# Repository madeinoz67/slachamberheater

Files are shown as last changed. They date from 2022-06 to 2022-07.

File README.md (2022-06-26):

# STR-21-007-SLAChamberHeater

SLA Chamber Heater for Resin Printers

## Project Features

* STR-21-007-SLAChamberHeater
* A starter KiCad project structured similar to <https://hackaday.com/2017/05/18/kicad-best-practises-library-management/>
* A starter documentation structure based on the <https://hutscape.com/pine/> by Sayanee Basu <https://github.com/sayanee> and her great youtube video around hardware documentation <https://youtu.be/uPitFGqjyPU>.

## Resources

Below are some handy resource links.

* [KiCad](https://www.kicad.org/) is a Cross Platform and Open Source Electronics Design Automation suite.
* [cookiecutter-kicad](https://github.com/madeinoz67/cookiecutter-kicad) a cookiecutter template for KiCad Projects.

## Authors

* **Stephen Eaton** - *Initial Work* - [github](https://github.com/madeinoz67)

See also the list of [contributors](https://github.com/madeinoz67/slachamberheater/AUTHORS.rst) who participated in this project.

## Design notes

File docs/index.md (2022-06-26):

# Welcome to STR-21-007-SLAChamberHeater

SLA Chamber Hearter for Resin Printers

--8<-- "./README.md"

    mkdocs.yml    # The configuration file.
    docs/
        index.md  # The documentation homepage.
        ...       # Other markdown pages, images and other files.

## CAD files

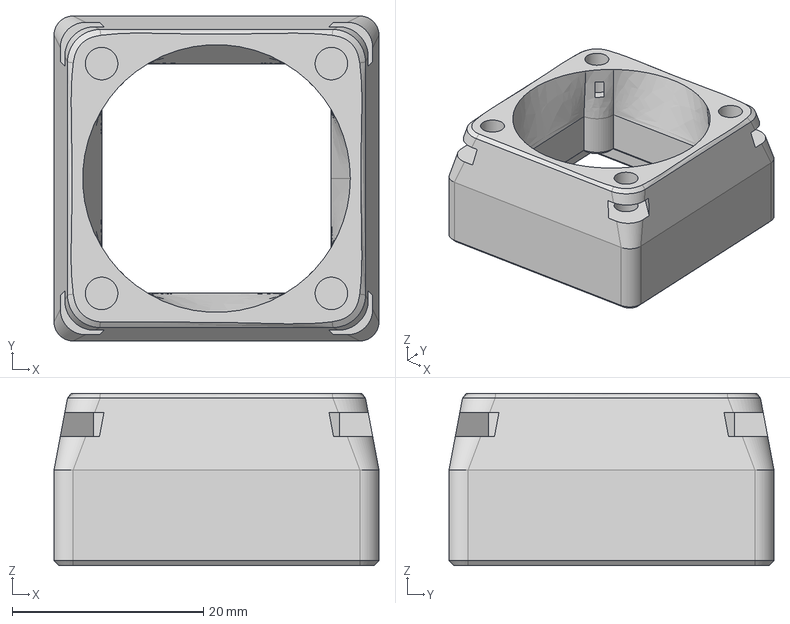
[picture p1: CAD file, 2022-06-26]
cad/V4/working/STR-21-007_assembly-rework2.FCStd
34.0 x 34.0 x 18.0 mm

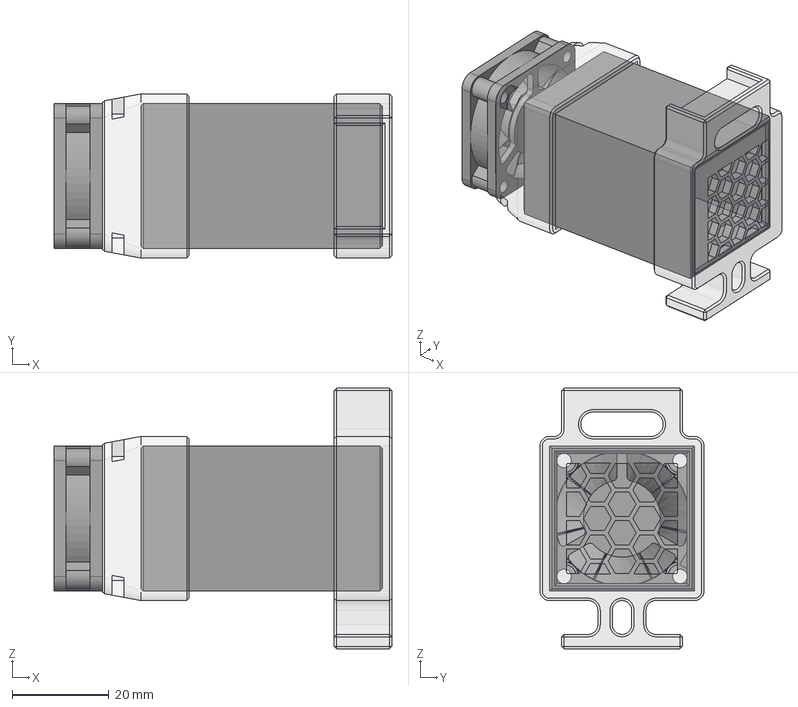
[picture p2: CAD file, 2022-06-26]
cad/V4/STR-21-007_assembly.FCStd
70.0 x 34.0 x 54.0 mm
InletBody
OutlerBody

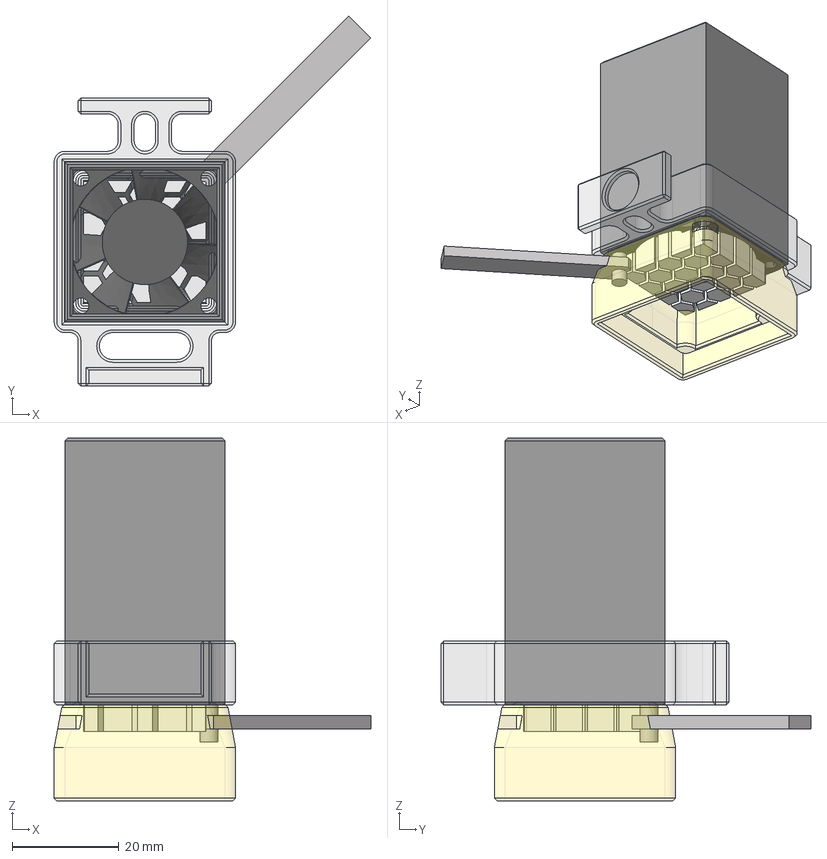
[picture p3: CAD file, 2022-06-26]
cad/V4/working/STR-21-007_assembly-rework1.FCStd
59.4 x 69.4 x 68.0 mm
Binder(Boolean001)
Binder001(Boolean001)
Binder002(BaseFeature)
M3 bolt and grooved nut
HoneycombBody
OutlerBody

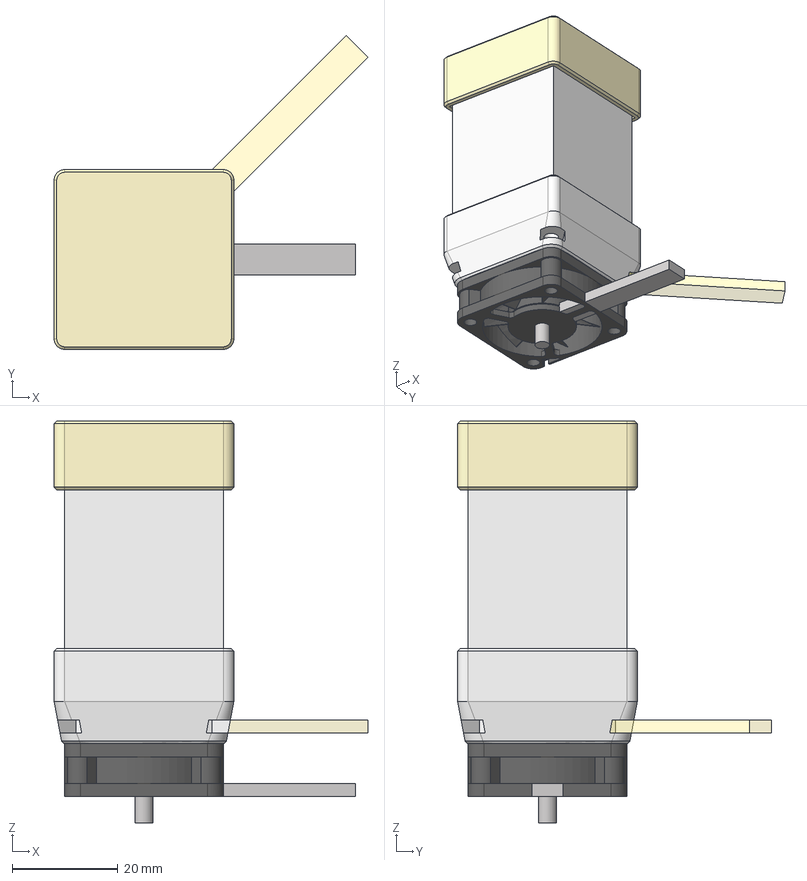
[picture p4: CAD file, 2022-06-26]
cad/V4/STR-21-007.FCStd
59.3 x 59.3 x 76.0 mm
Binder(_3mmNut)
Inlet_Housing_Body
TubeBody
BooleanBody
Chamfer001Body
M3 bolt and grooved nut
Import004(Chamfer001)
OutletHousingBody
Pad001Body

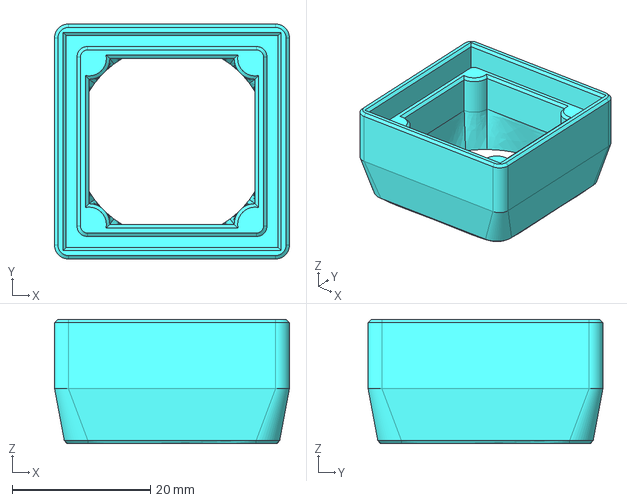
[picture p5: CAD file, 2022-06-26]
cad/V4/V4.1/STR-21-007.FCStd
34.0 x 34.0 x 18.0 mm

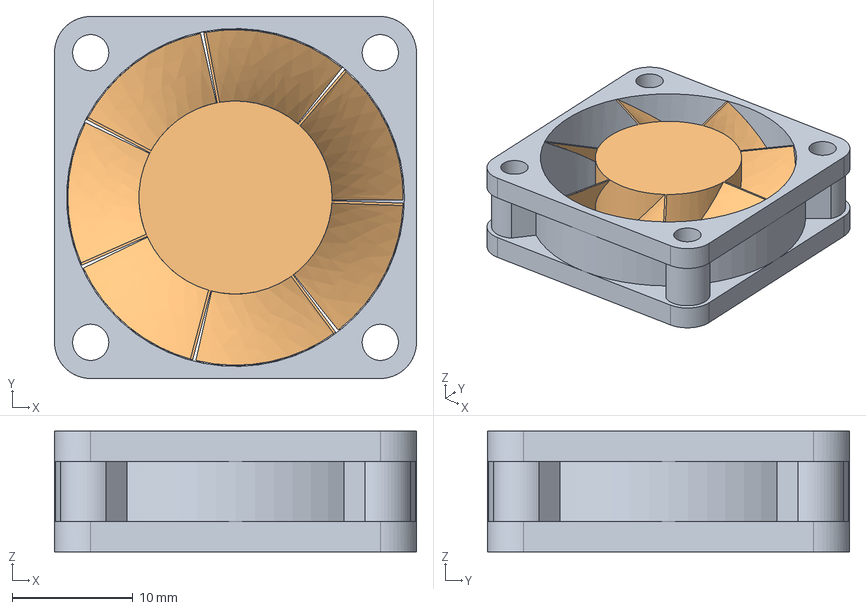
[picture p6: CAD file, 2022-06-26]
cad/Parts/30mmFan.FCStd
30.0 x 30.0 x 10.0 mm

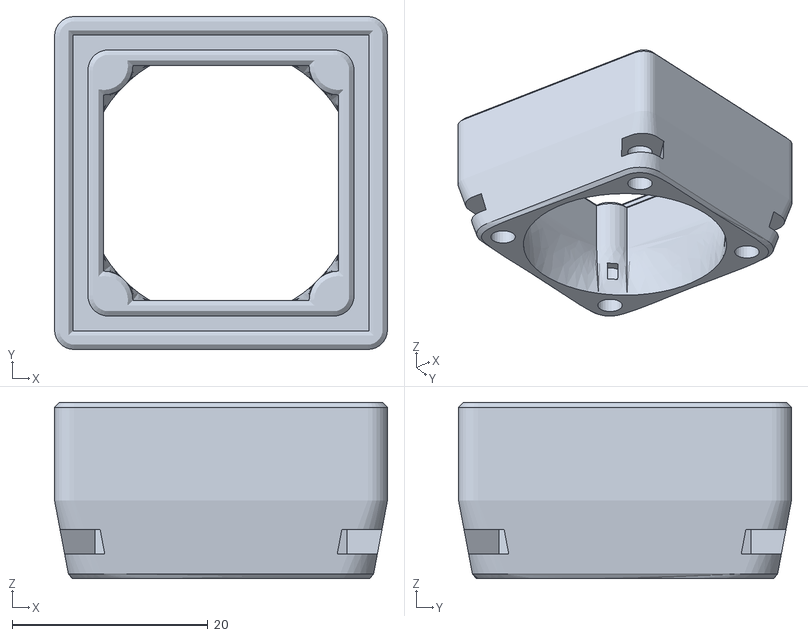
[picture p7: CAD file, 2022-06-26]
cad/STR-21-007-Resin_Heater--master_heater.stl
34.0 x 34.0 x 18.0

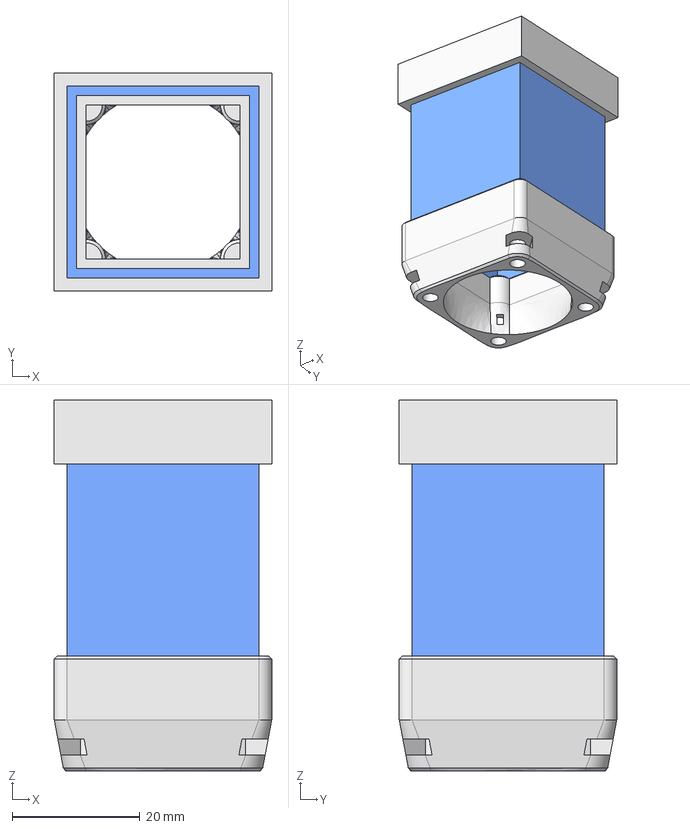
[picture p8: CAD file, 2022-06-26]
cad/STR-21-007-Resin_Heater.FCStd
34.0 x 34.0 x 58.0 mm
Inlet_housing
AL_sqrtube30x30
Outlet_housing

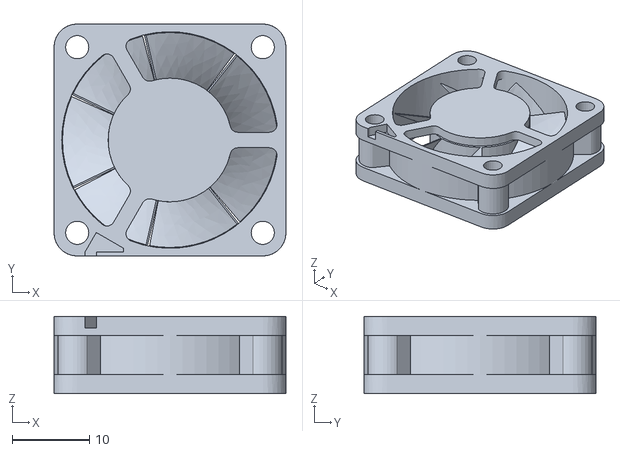
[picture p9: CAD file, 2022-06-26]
cad/STR-21-007-Resin_Heater--30mm_Axial_Fan.stl
30.0 x 30.0 x 10.0

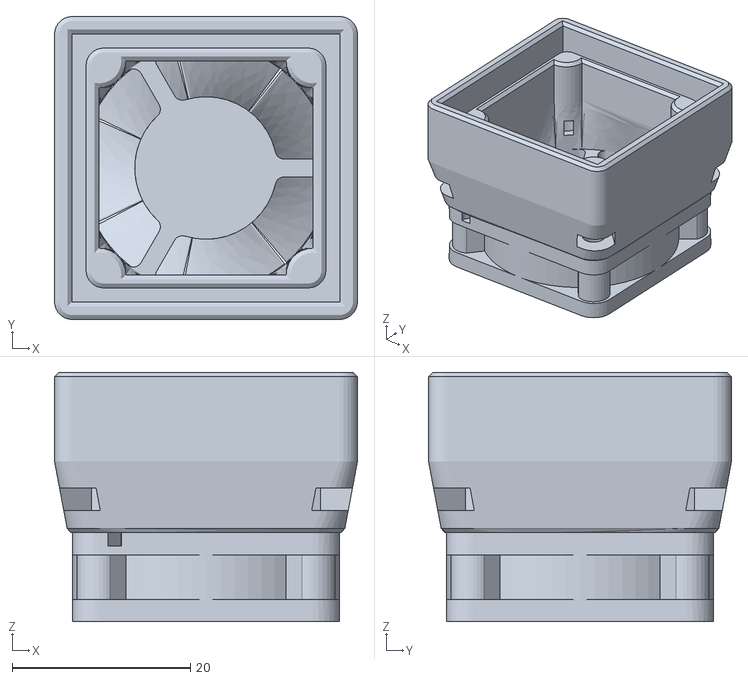
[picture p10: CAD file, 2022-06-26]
cad/STR-21-007-Resin_Heater--Resin_Heater.stl
34.0 x 34.0 x 28.0

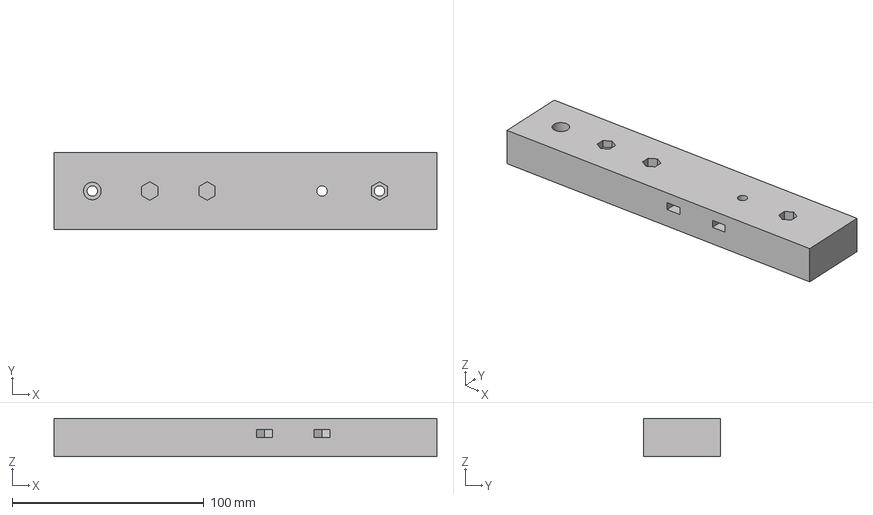
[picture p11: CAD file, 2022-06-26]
cad/Parts/Bolts and nuts holes.FCStd
200.0 x 40.0 x 20.0 mm

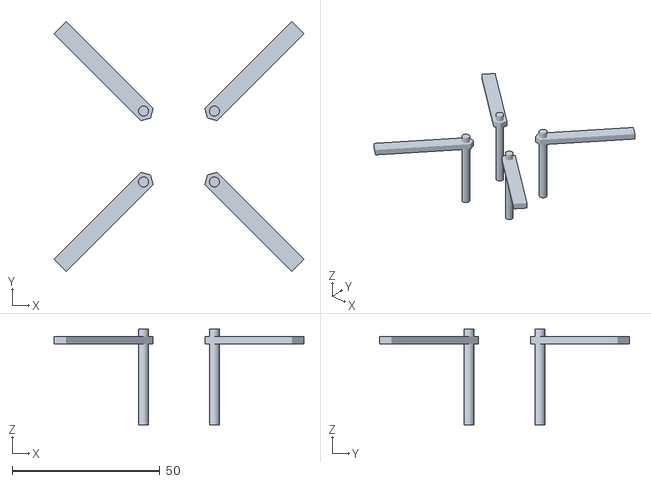
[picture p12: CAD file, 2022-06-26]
cad/STR-21-007-Resin_Heater--Reference(M3 Nut Tool).stl
84.7 x 84.7 x 32.5

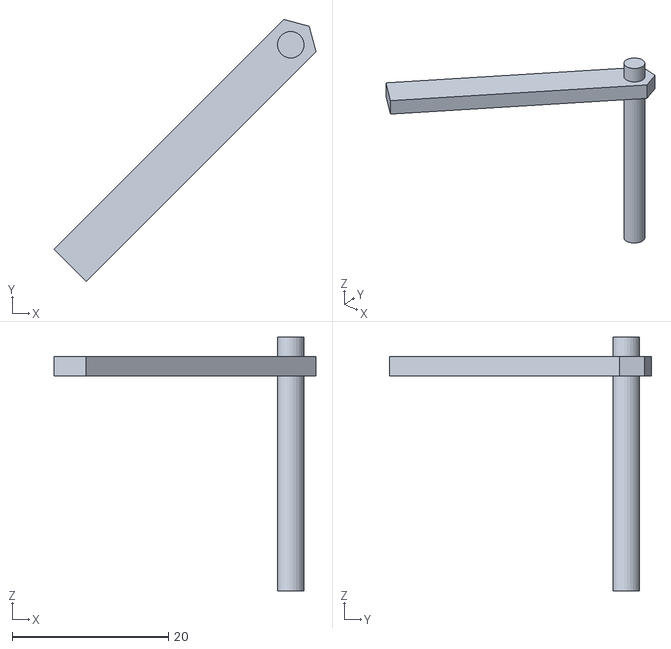
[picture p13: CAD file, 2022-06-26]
cad/STR-21-007-Resin_Heater--M3 bolt and grooved nut tool.stl
33.6 x 33.6 x 32.5

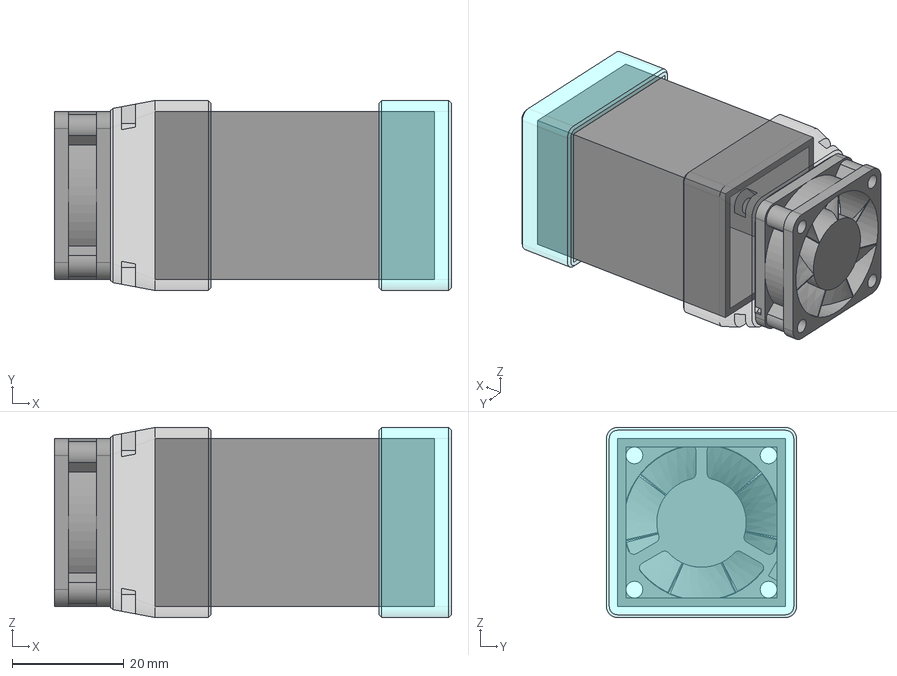
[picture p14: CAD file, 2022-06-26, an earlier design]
cad/V4/backup/STR-21-007_assembly.FCStd
71.0 x 34.0 x 34.0 mm
InletBody
OutletBody

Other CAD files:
cad/V3-Fixed/STR-21-007-Resin_Heater.FCStd
cad/Parts/fan_30mm_axial.step
cad/STR-21-007-Resin_Heater--Inlet_housing.stl
cad/v1/STR-21-007-SLAChamberHeater_v2--Reference002(Honeycomb mask).stl
cad/V3/STR-21-007-Resin_Heater.FCStd
cad/V4/STR-21-007_.FCStd
cad/v1/STR-21-007-SLAChamberHeater.FCStd
cad/v1/STR-21-007-SLAChamberHeater_v2--Body002.stl
cad/v1/STR-21-007-SLAChamberHeater_v2--Body006.stl
cad/v1/STR-21-007-SLAChamberHeater_v2--Fillet002.stl
cad/v1/STR-21-007-SLAChamberHeater_v2--Heater Body.stl
cad/v1/STR-21-007-SLAChamberHeater_v2--Inlet Housing.stl
cad/v1/STR-21-007-SLAChamberHeater_v2--M3 bolt and grooved nut.stl
cad/v1/STR-21-007-SLAChamberHeater_v2--Outlet Housing.stl
cad/v1/STR-21-007-SLAChamberHeater_v2--Reference(aluminium sqr tube).stl
cad/v1/STR-21-007-SLAChamberHeater_v2--Reference001(aluminium sqr tube).stl
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

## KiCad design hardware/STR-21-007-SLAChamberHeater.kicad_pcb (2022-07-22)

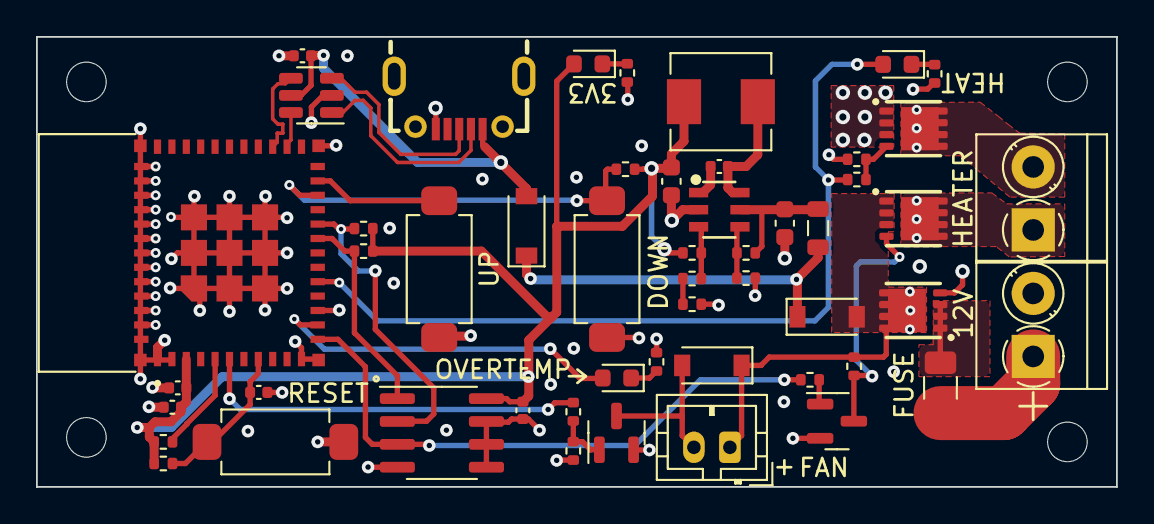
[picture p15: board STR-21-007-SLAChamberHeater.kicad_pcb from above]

Board: 4 copper layers, 60.0 x 25.0 mm, 56 parts (0 on the bottom side), 36 nets.

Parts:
C101: 10n; C_0402_1005Metric
C102: 10u; C_0603_1608Metric
C103: 22u; C_0603_1608Metric
C201: 10u; C_0402_1005Metric
C202: 1u; C_0402_1005Metric
C203, C204, C301: 100n; C_0402_1005Metric
D101, D102: B5819W; D_SOD-123
D301: 1N4148W; D_SOD-123
F101: 5A; Fuse_1206_3216Metric
FB101: 600@600MHz; L_0805_2012Metric
H1, H2, H3, H4: MountingHole; MountingHole_2.2mm_M2
J101: 2.5mm; TerminalBlock_Phoenix_PT-1,5-2-3.5-H_1x02_P3.50mm_Horizontal
J301: HEATER; TerminalBlock_Phoenix_PT-1,5-2-3.5-H_1x02_P3.50mm_Horizontal
J302: FAN; JST_PH_B2B-PH-K_1x02_P2.00mm_Vertical
L101: 10u; L_Sunlord_MWSA0518_5.4x5.2mm
LED101: Green; LED_0603_1608Metric
LED301: Blue; LED_0603_1608Metric
LED302: Red; LED_0603_1608Metric
Q101, Q302: RU30L30M3; DFN-8_L3.0-W3.0-P0.65-BL
Q301, Q304: BSS138; SOT-23
Q303: RU3070M3; DFN-8_L3.0-W3.0-P0.65-BL
R101: 100K; R_0402_1005Metric
R102: 68K; R_0402_1005Metric
R103: 47K; R_0402_1005Metric
R104: 15K; R_0402_1005Metric
R105: 270; R_0402_1005Metric
R106, R306, R308: 1K5; R_0402_1005Metric
R201, R202, R205, R303, R304, R307: 10K; R_0402_1005Metric
R203, R204: 2k2; R_0402_1005Metric
R301, R302, R305: 100R; R_0402_1005Metric
SW201, SW202, SW401: SW_Push; SW_SMD_SPST_8x3.6
U101: MP2359DJ-LF-Z; SOT-23-6_L2.9-W1.6-P0.95-LS2.8-BL
U201: ESP32-C3-MINI-1-N4
U202: USBLC6-2SC6; SOT-23-6
U301: LM75BDP; SOIC-8_3.9x4.9mm_P1.27mm
USB201: U-F-M5DD-Y-L; MICRO-USB-SMD_MICRO-USB-18

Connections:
12V_FUSED: D101.2 (A), D301.1 (K), J302.1, Q101.5 (D), Q101.6 (D), Q101.7 (D), Q101.8 (D), Q101.9 (D), Q302.1 (S), Q302.2 (S), Q302.3 (S), R303.2
+3V3: C103.1, C201.1, C203.1, C301.1, L101.2, LED101.2 (A), R103.1, R201.1, R202.1, R203.1, R204.1, R205.1, U201.3 (3V3), U301.8 (+Vs)
+12V: F101.1, J101.1
/[1] Power/FUSE_S: F101.2, Q101.1 (S), Q101.2 (S), Q101.3 (S)
/[2] MCU/BOOT: SW202.2, U201.23 (IO9)
/[2] MCU/EN: C202.1, R202.2, SW201.2, U201.8 (EN)
/[2] MCU/USB_CONN_D+: U202.3 (I/O2), USB201.3 (D+)
/[2] MCU/USB_CONN_D-: U202.1 (I/O1), USB201.2 (D-)
/[2] MCU/USB_D+: U201.27 (IO19), U202.4 (I/O2)
/[2] MCU/USB_D-: U201.26 (IO18), U202.6 (I/O1)
/[3] Heater/FAN_CONN_2: D301.2 (A), J302.2, Q304.3 (D)
/[3] Heater/FAN_G: Q304.1 (G), R305.2, R307.2
/[3] Heater/HEAT_CONN_1: J301.1, Q302.5 (D), Q302.6 (D), Q302.7 (D), Q302.8 (D), Q302.9 (D)
/[3] Heater/HEAT_CONN_2: J301.2, Q303.5 (D), Q303.6 (D), Q303.7 (D), Q303.8 (D), Q303.9 (D)
/[3] Heater/HEAT_G: Q303.4 (G), R302.2, R304.2
/[3] Heater/OT_DRV_G: Q301.1 (G), R301.2
/[3] Heater/OT_G: Q301.3 (D), Q302.4 (G), R303.1
BTN1: R205.2, SW401.2, U201.22 (IO8)
BUCK_BST: C101.1, U101.1 (BST)
BUCK_EN: R101.2, R102.1, U101.4 (EN)
BUCK_FB: R103.2, R104.1, U101.3 (FB)
BUCK_IN: C102.1, FB101.2, R101.1, U101.5 (IN)
BUCK_SW: C101.2, L101.1, U101.6 (SW)
FAN: R305.1, U201.6 (IO3)
GND: C102.2, C103.2, C201.2, C202.2, C203.2, C204.2, C301.2, J101.2, Q101.4 (G), Q301.2 (S), Q303.1 (S), Q303.2 (S), Q303.3 (S), Q304.2 (S), R102.2, R105.2, R106.2, R304.1, R306.2, R307.1, R308.2, SW201.1, SW202.1, SW401.1, U101.2 (GND), U201.1 (GND), U201.2 (GND), U201.11 (GND), U201.14 (GND), U201.36 (GND), U201.37 (GND), U201.38 (GND), U201.39 (GND), U201.40 (GND), U201.41 (GND), U201.42 (GND), U201.43 (GND), U201.44 (GND), U201.45 (GND), U201.46 (GND), U201.47 (GND), U201.48 (GND), U201.49_1 (GND), U201.49_2 (GND), U201.49_3 (GND), U201.49_4 (GND), U201.49_5 (GND), U201.49_6 (GND), U201.49_7 (GND), U201.49_8 (GND), U201.49_9 (GND), U201.50 (GND), U201.51 (GND), U201.52 (GND), U201.53 (GND), U202.2 (GND), U301.4 (GND), U301.5 (A2), U301.6 (A1), U301.7 (A0), USB201.5 (GND)
HEATER: LED301.2 (A), R302.1, U201.16 (IO10)
I2C1_SCL: R204.2, U201.20 (IO6), U301.2 (SCL)
I2C1_SDA: R203.2, U201.19 (IO5), U301.1 (SDA)
unnamed: D101.1 (K), D102.1 (K), FB101.1
unnamed: LED101.1 (K), R106.1
unnamed: LED301.1 (K), R306.1
unnamed: LED302.1 (K), R308.1
unnamed: R104.2, R105.1
OVERTEMP: LED302.2 (A), U201.13 (IO1)
VBUS: C204.1, D102.2 (A), U202.5 (VBUS), USB201.1 (VCC)
~INT_OVERTEMP: R301.1, U201.12 (IO0), U301.3 (O.S.)

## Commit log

2022-06-26 initial project commit
    [30mmFan.FCStd, Bolts and nuts holes.FCStd, STR-21-007-Resin_Heater--30mm_Axial_Fan.stl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]
2022-06-26 Added kicad-library submodule
2022-06-27 started sheet
    [STR-21-007-SLAChamberHeater.kicad_sch]
2022-07-04 split out sheets
    Fixed grid
    Added datasheets
    [Analogue.kicad_sch, Heater.kicad_sch, MCU.kicad_sch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]
2022-07-10 spice model for Heater circuit
2022-07-10 Added .gitignore for KICAD at hardware level
2022-07-10 schematics finished, footprints assigned. Still need to fix foorptints for MOSFETS
    [Heater.kicad_sch, MCU.kicad_sch, Power.kicad_sch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]
2022-07-10 removed .kicad_prl from repo and added to .gitignore
2022-07-11 footprint update for MOSFETS to PDFN3333
    [Heater.kicad_sch, Power.kicad_sch, STR-21-007-SLAChamberHeater.kicad_pcb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]
2022-07-15 routing and foot print changes
    [Heater.kicad_sch, MCU.kicad_sch, Power.kicad_sch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]
2022-07-22 updated for kibot
    [STR-21-007-SLAChamberHeater.kicad_pcb, STR-21-007-SLAChamberHeater.kicad_sch]
2022-07-22 corrected kibot version for kicad 6
2022-07-22 DRC filter

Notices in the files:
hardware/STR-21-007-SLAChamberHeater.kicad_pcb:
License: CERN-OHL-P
